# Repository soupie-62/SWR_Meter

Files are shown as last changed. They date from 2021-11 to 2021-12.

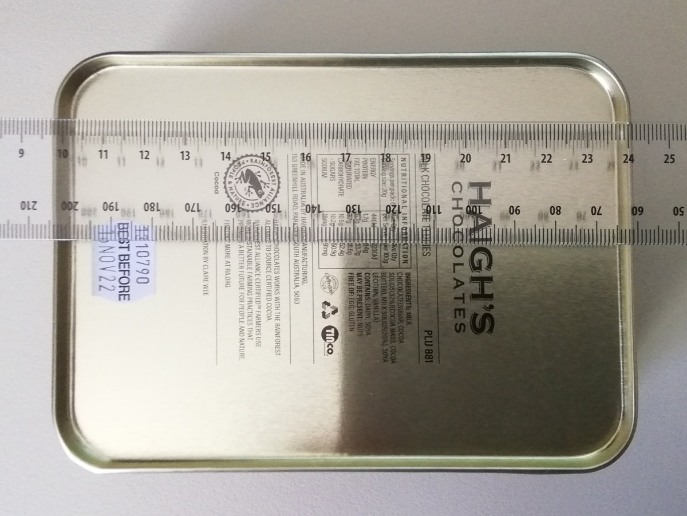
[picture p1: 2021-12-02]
Notes/10cm_12cm_Container_2.jpg

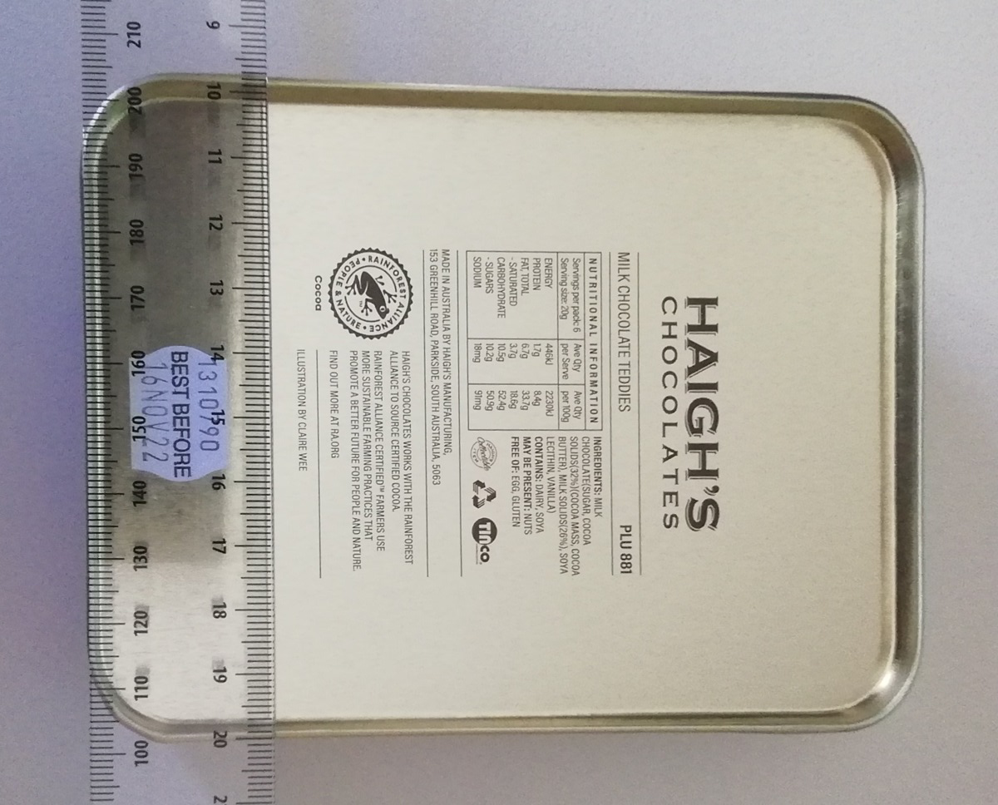
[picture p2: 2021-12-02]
Notes/10cm_12cm_Container_1.jpg

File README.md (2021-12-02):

# SWR_Meter
Notes on an SWR meter. Directional coupler PCB

If you want to truly understand something, try building it. In this, I'm trying to understand directional couplers, as used in SWR meters.

The most basic version is a "sensor" track, very close to the main PCB track. This is only good when the length of track is a significant portion of frequency wavelength.
You could make the PCB longer, but the size limit for cheap PCBs is 10cm x 10cm (4 inch x 4 inch old scale).

At lower frequencies, the "stockton" circuit uses toroid transformers to sense the source voltage and current. The frequency range becomes a function of the toroids used.

My circuit:
I want to create coils from PCB tracks, keeping the Stockton design but eliminating the toroidal transformers. 

SWR_pcb_V2-3

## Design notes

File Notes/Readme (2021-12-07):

Assorted files saved here
PCB Spiral from: https://www.semanticscholar.org/paper/Compact-monolithic-spiral-quadrature-coupler-design-Tabarani-Schumacher/7f18878f872b617d588d85db786c9b51f7185a0d

07 Dec 2021:
Facebook KICAD User Group member, Enrico Lia, has modelled the board using Sonnet and CST Studio.
Results are added

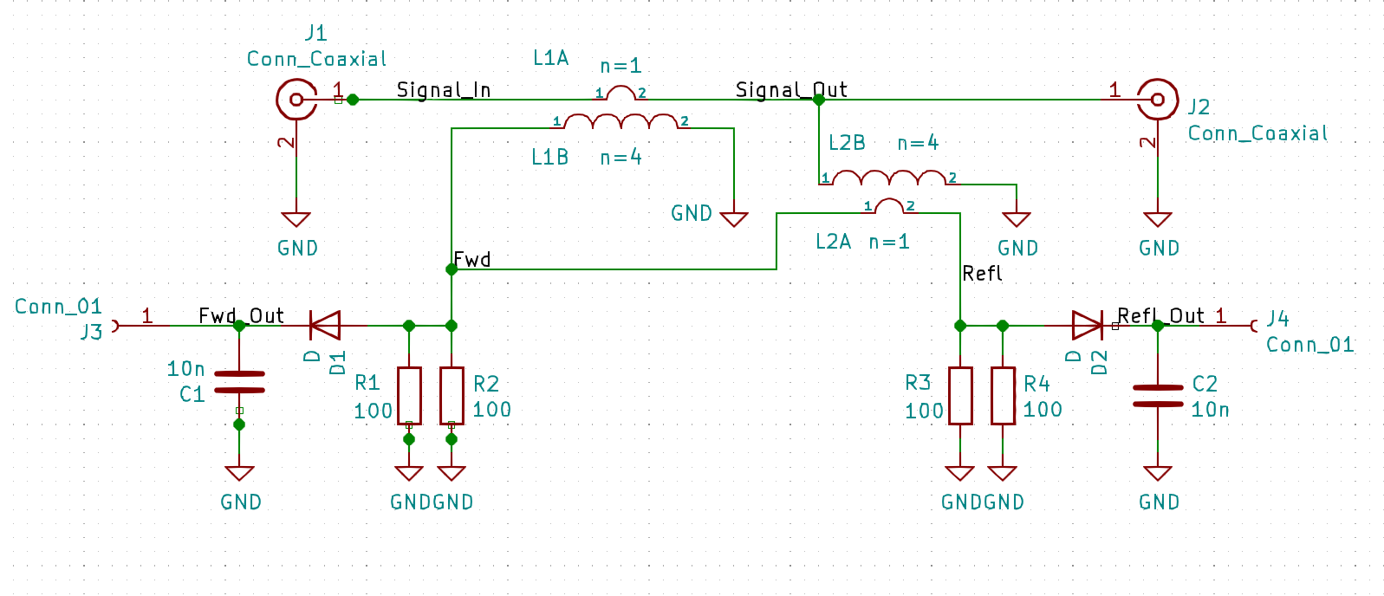
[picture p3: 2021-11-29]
Ver_2/Schematic_KiCad.png

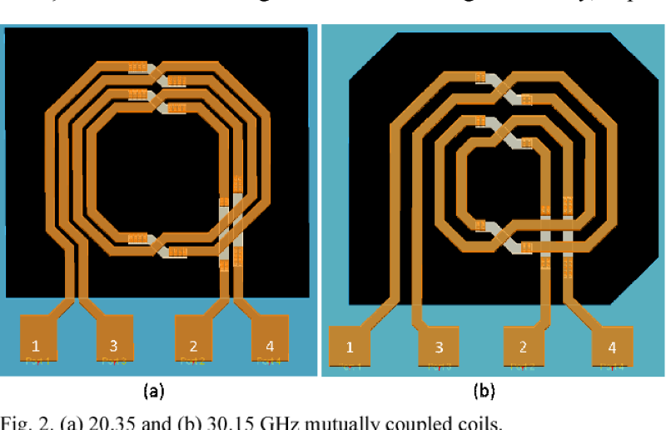
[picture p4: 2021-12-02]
Notes/Spiral_SAMPLE_20GHz.png

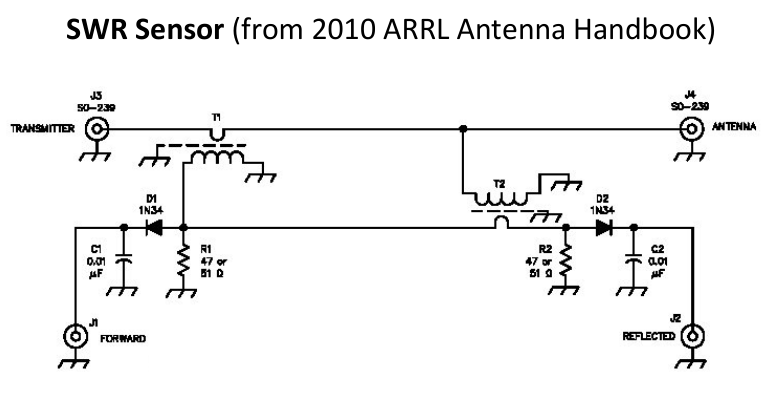
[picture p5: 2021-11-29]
Notes/circuit-02-ARRL.png

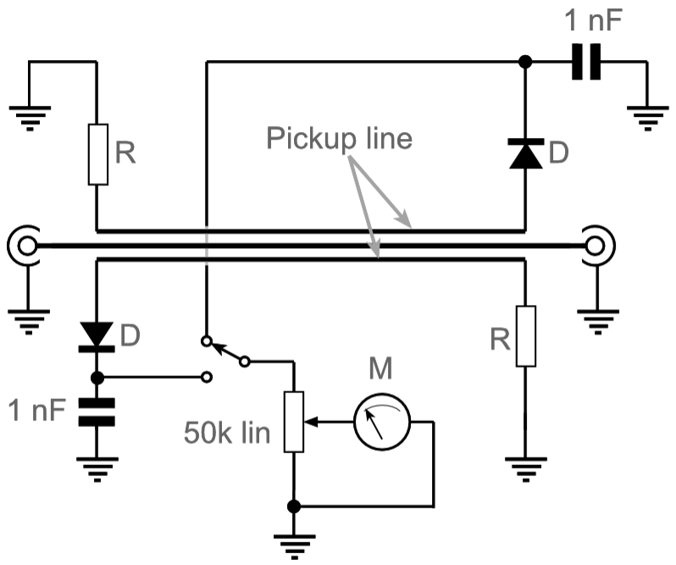
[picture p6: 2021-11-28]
Notes/circuit-01-vswr.png

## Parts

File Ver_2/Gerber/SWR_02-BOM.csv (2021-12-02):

Comment | Designator | Footprint | JLCPCB Part #?optional?
Conn_Coaxial | J1
Conn_Coaxial | J2
100 Ohm | R1 | 2010 SMD | C50472
100 Ohm | R2 | 2010 SMD | C50472
100 Ohm | R3 | 2010 SMD | C50472
100 Ohm | R4 | 2010 SMD | C50472
10nF | C1 | 1812 SMD | C426626
10nF | C2 | 1812 SMD | C426626
BAT46 | D2 | SOD123 | C283255
BAT46 | D1 | SOD123 | C283255
Conn_01x01_Female | J4
Conn_01x01_Female | J3

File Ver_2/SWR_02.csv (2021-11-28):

Reference | Value | Footprint | Datasheet
J1 | Conn_Coaxial |  | ~
J2 | Conn_Coaxial |  | ~
R4 | 100 |  | ~
R3 | 100 |  | ~
R1 | 100 |  | ~
R2 | 100 |  | ~
D2 | D |  | ~
D1 | D |  | ~
C1 | 10n |  | ~
C2 | 10n |  | ~
J4 | Conn_01x01_Female |  | ~
J3 | Conn_01x01_Female |  | ~

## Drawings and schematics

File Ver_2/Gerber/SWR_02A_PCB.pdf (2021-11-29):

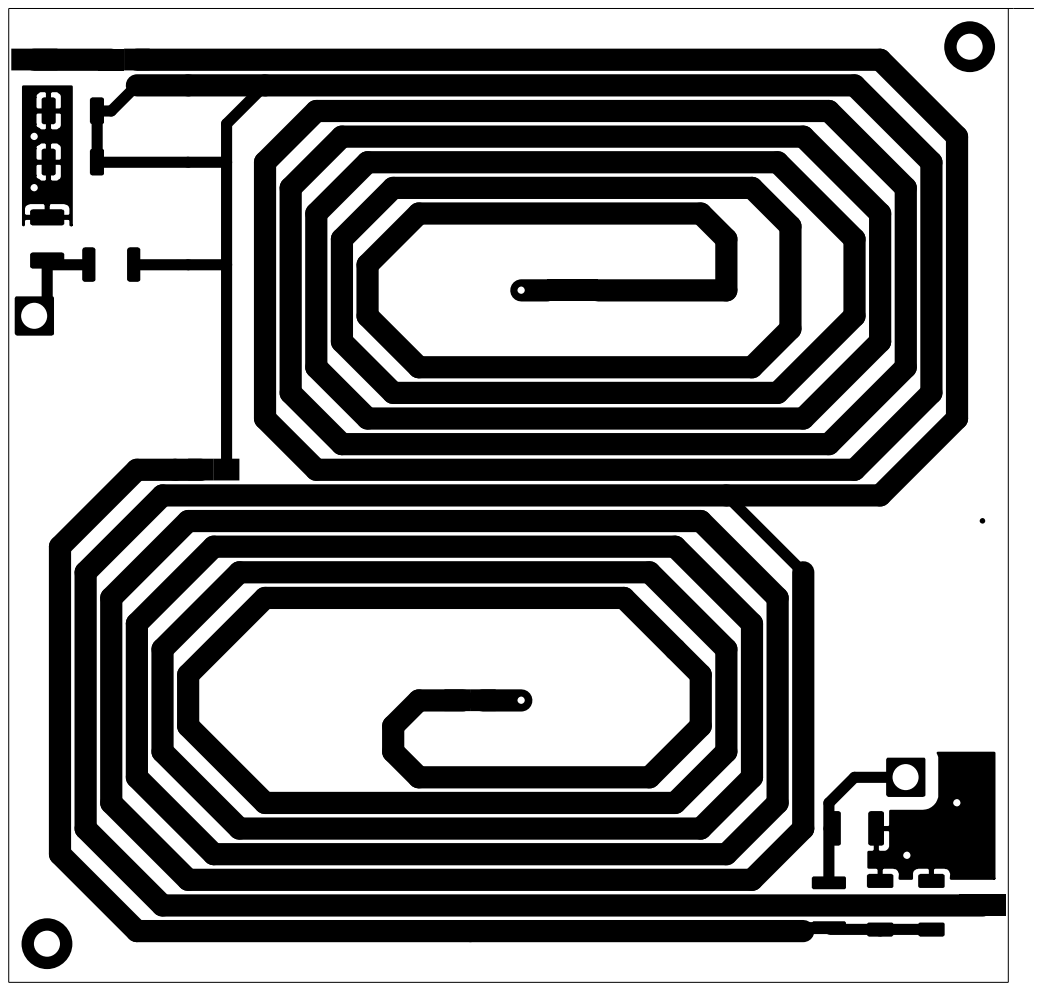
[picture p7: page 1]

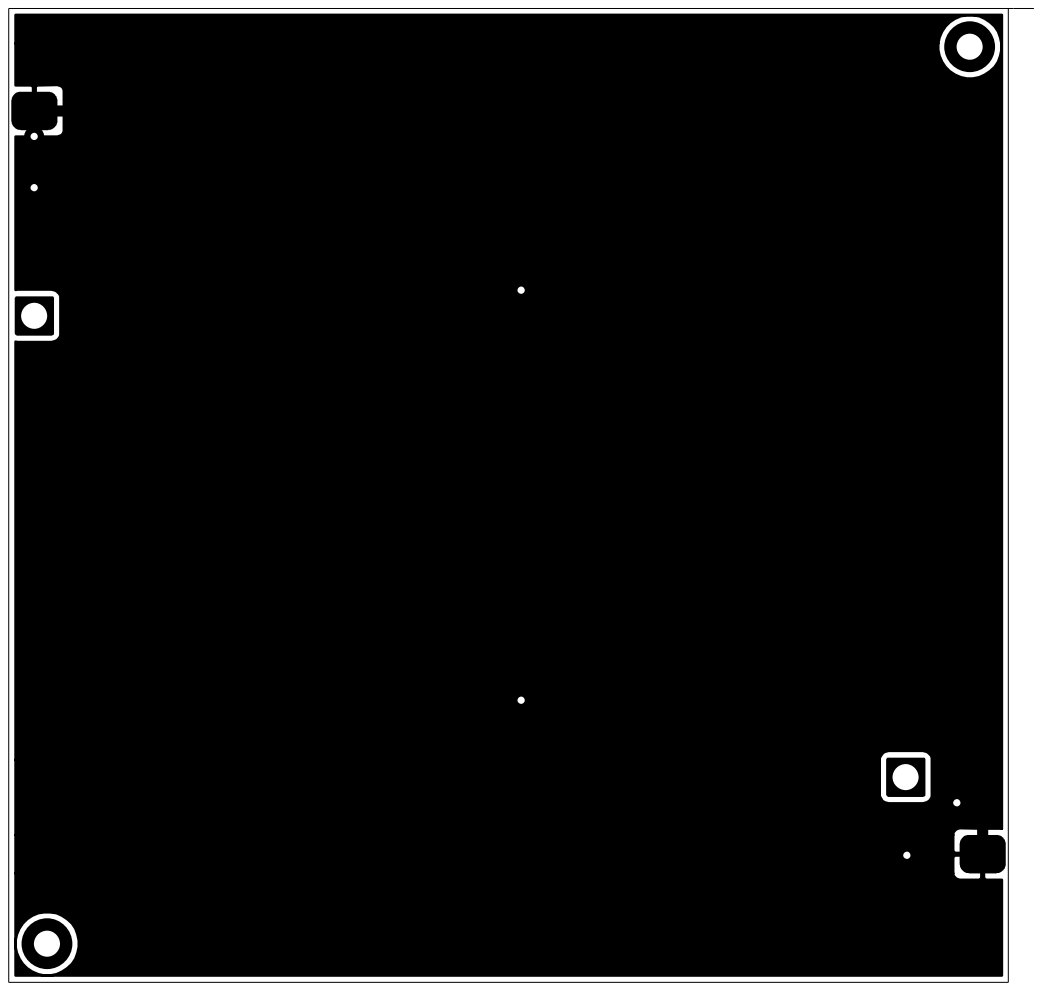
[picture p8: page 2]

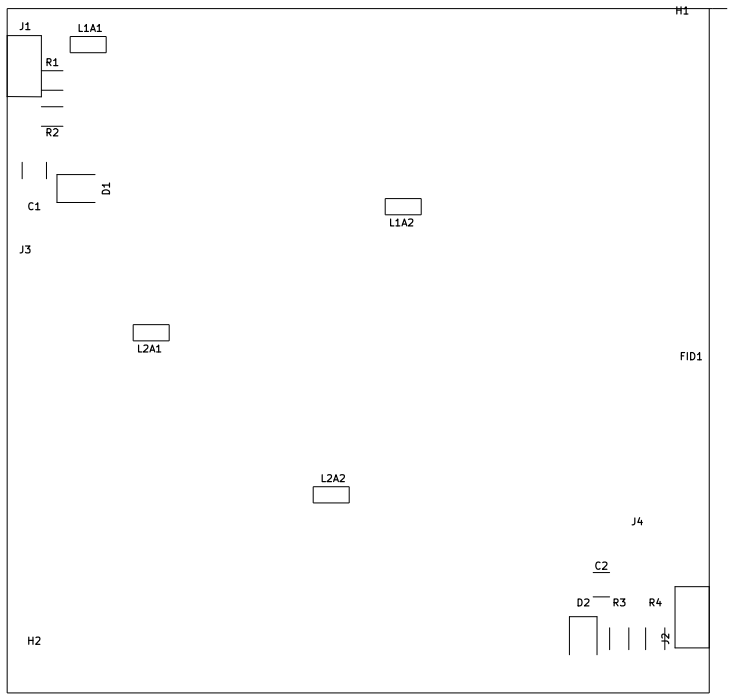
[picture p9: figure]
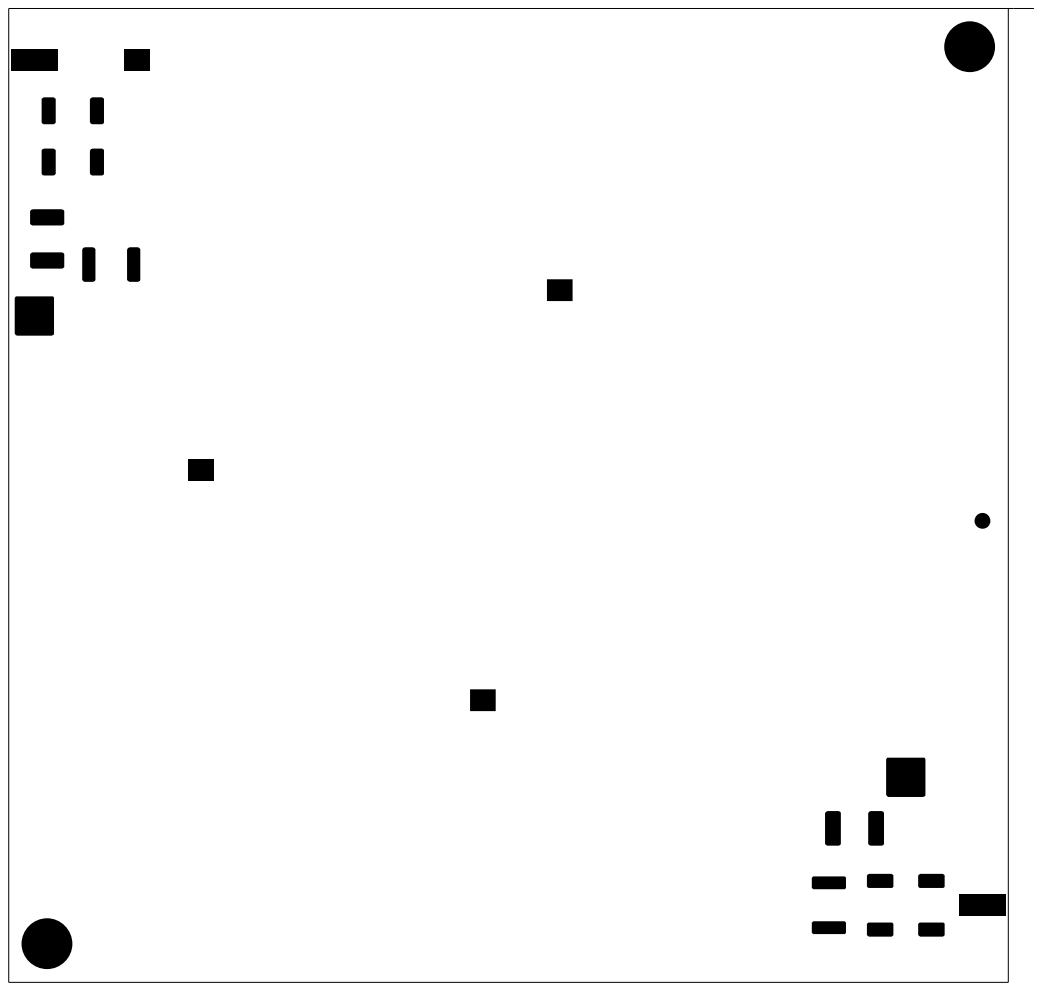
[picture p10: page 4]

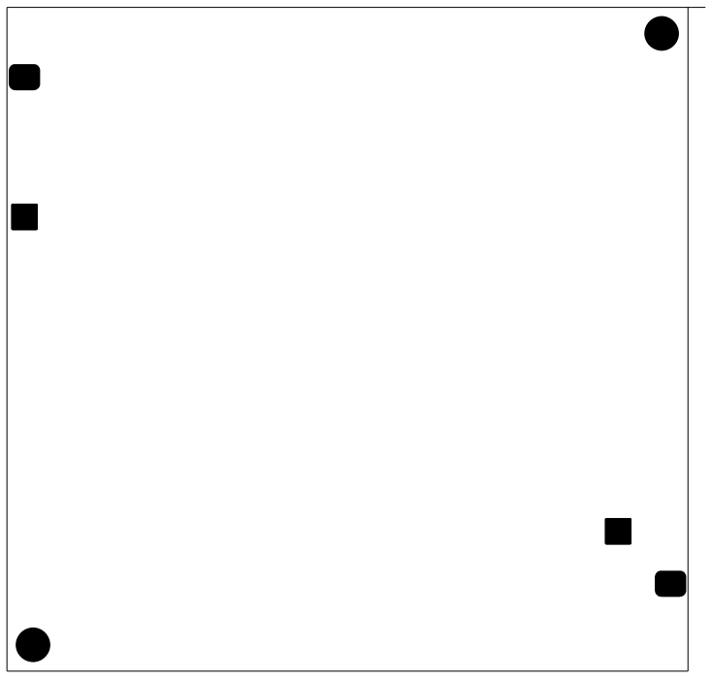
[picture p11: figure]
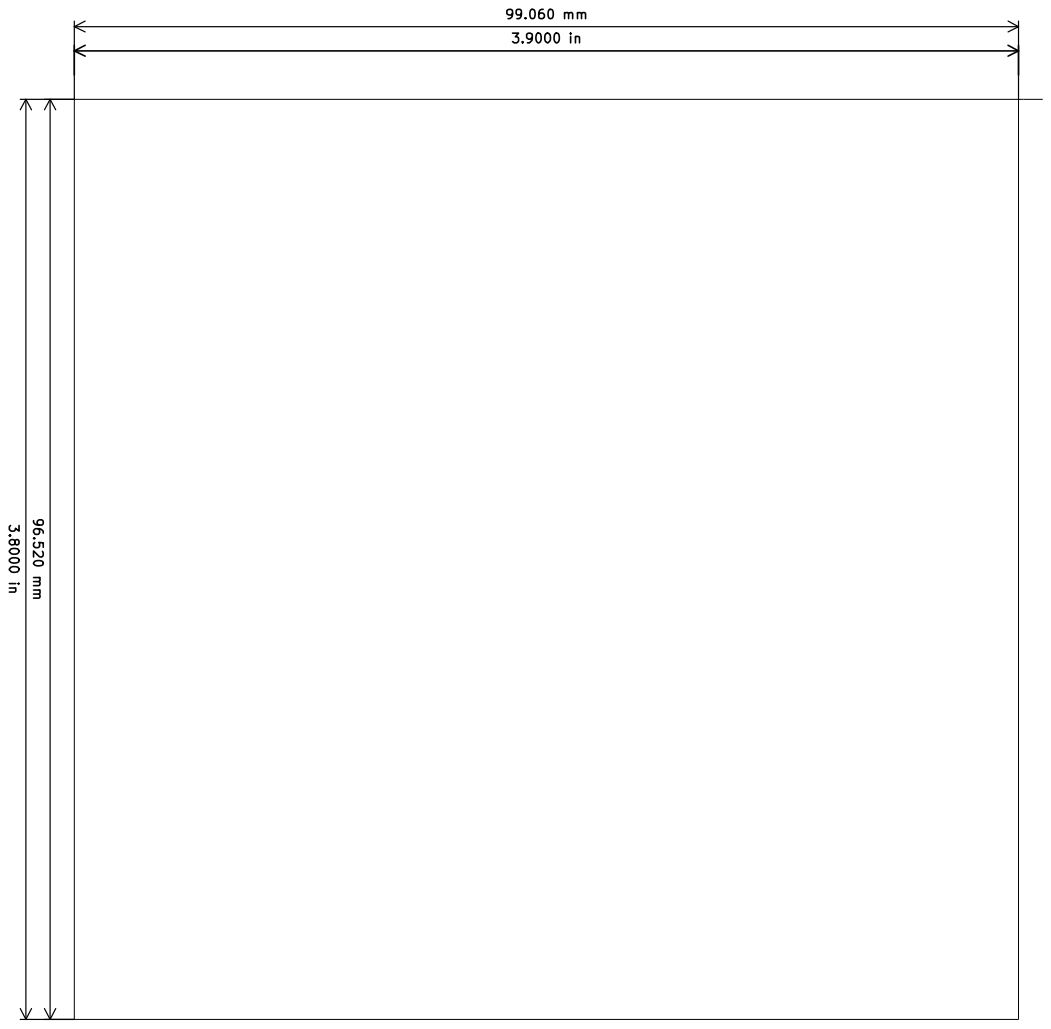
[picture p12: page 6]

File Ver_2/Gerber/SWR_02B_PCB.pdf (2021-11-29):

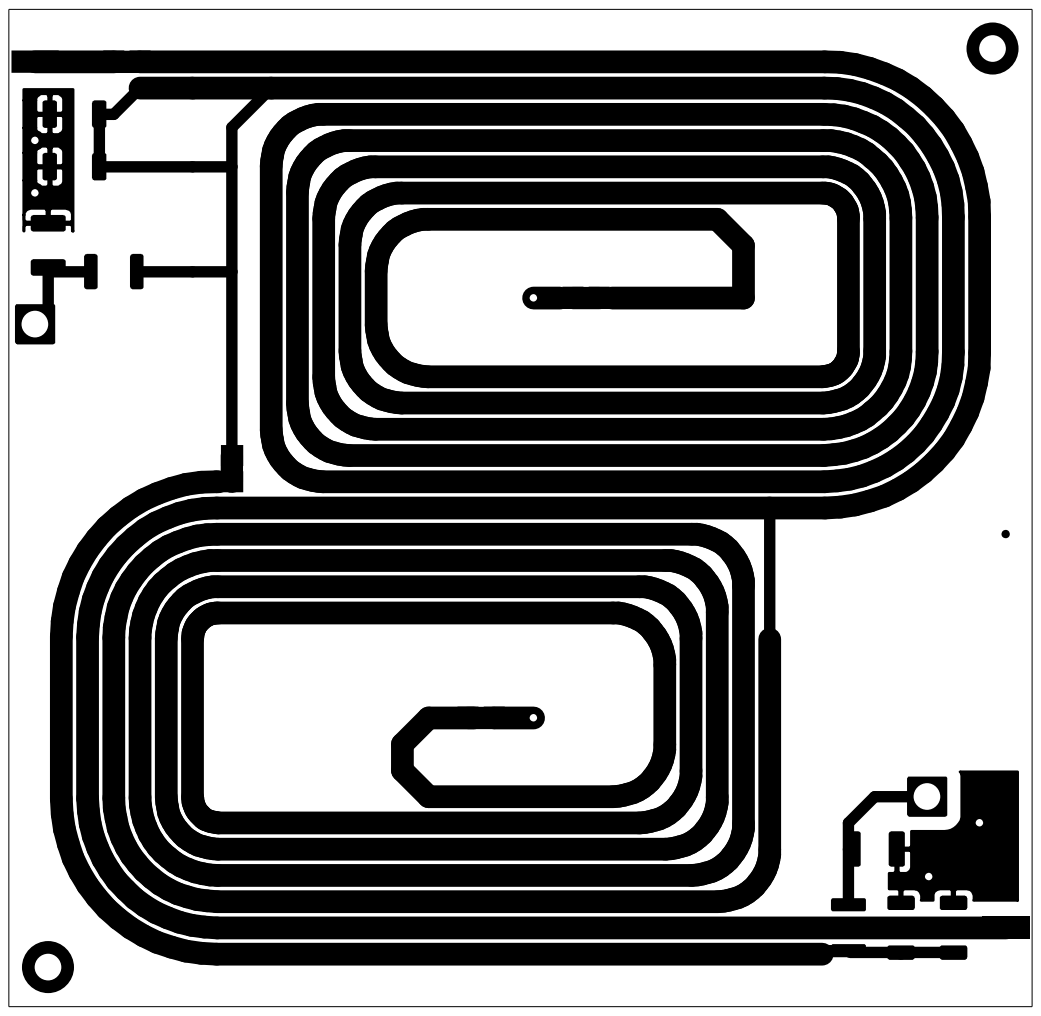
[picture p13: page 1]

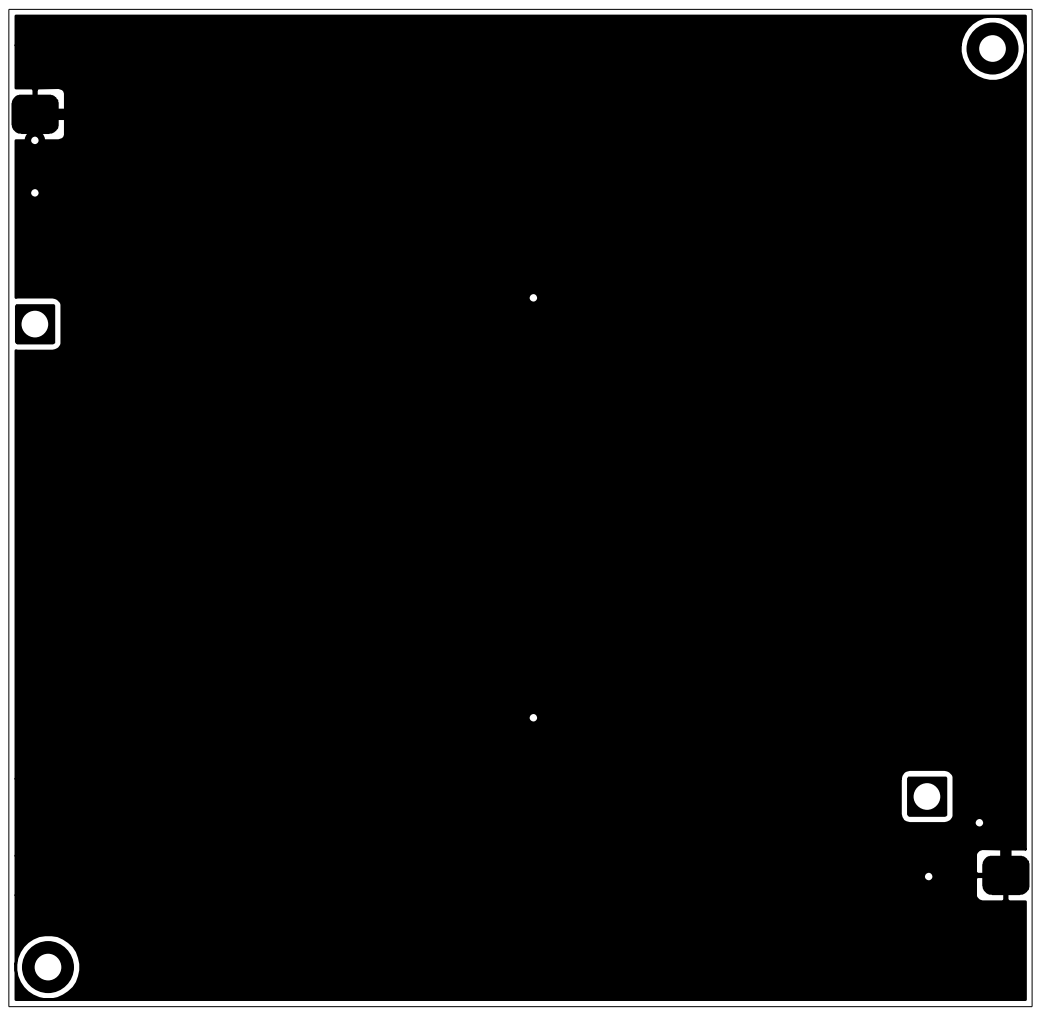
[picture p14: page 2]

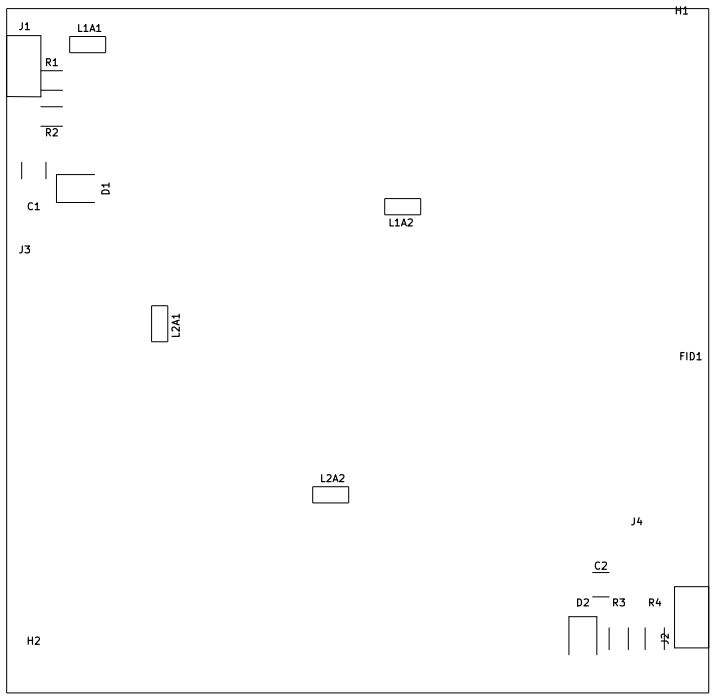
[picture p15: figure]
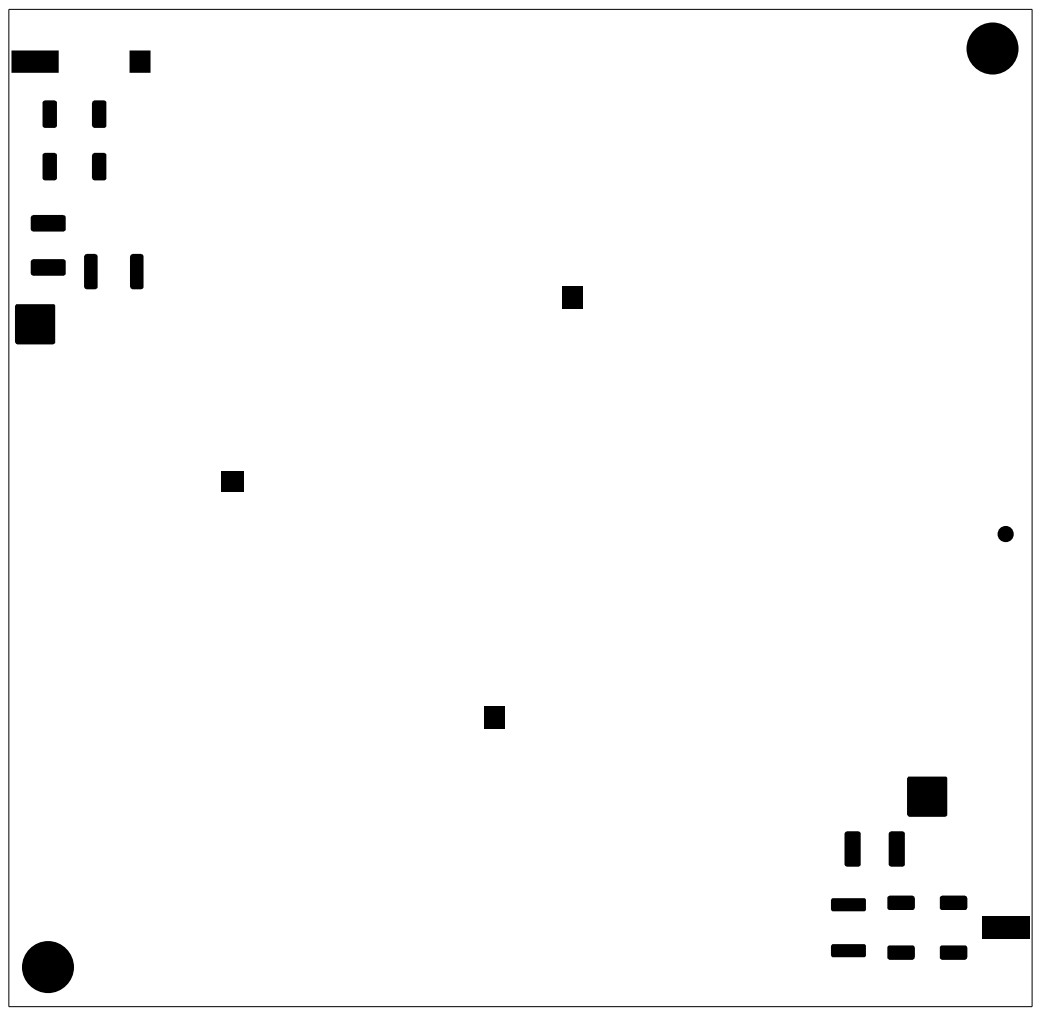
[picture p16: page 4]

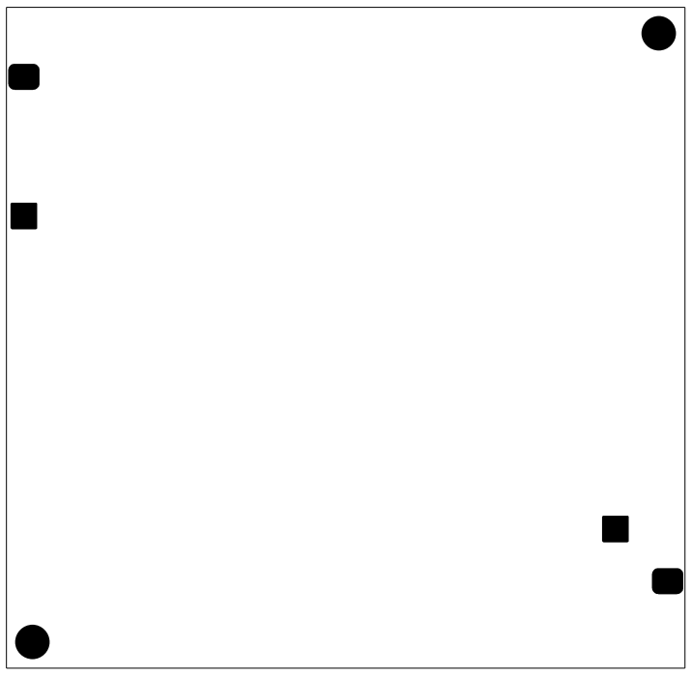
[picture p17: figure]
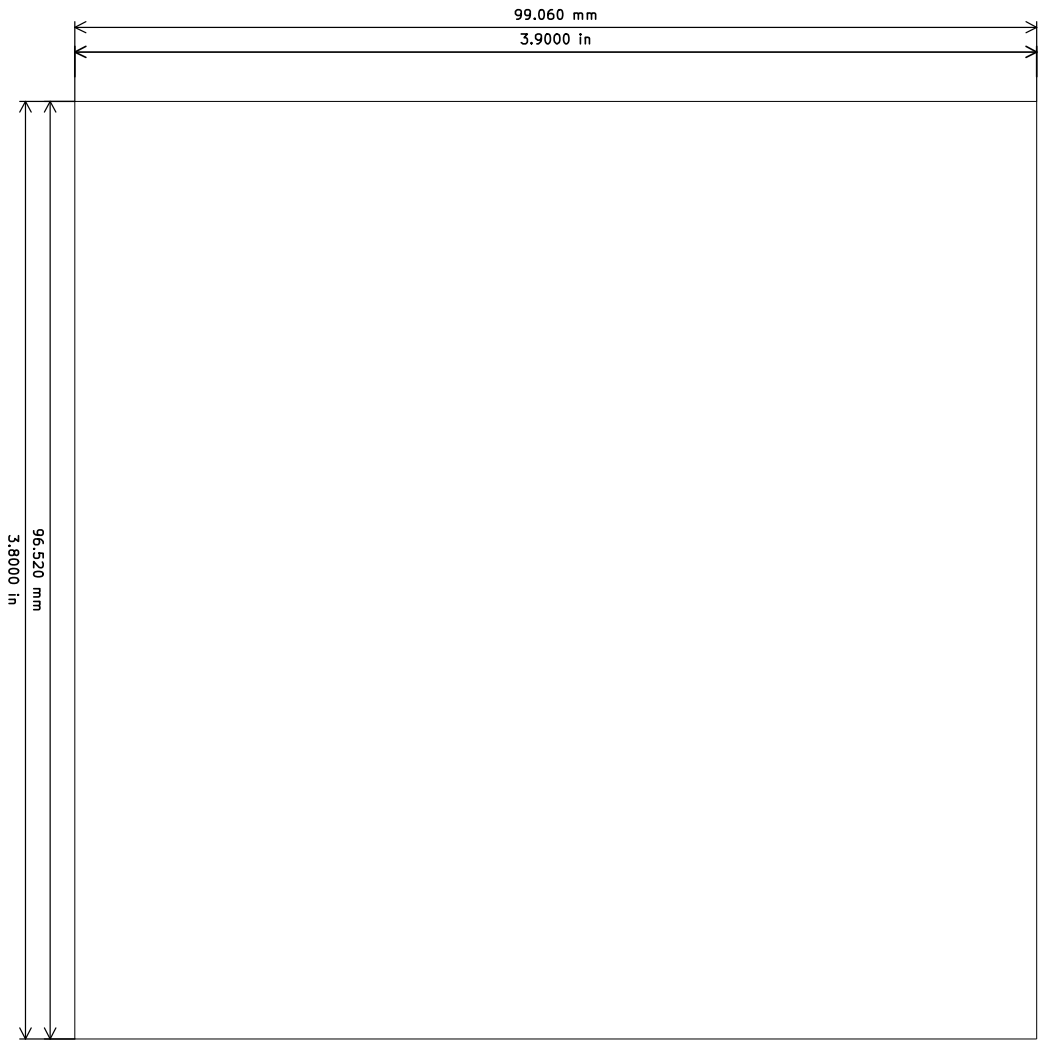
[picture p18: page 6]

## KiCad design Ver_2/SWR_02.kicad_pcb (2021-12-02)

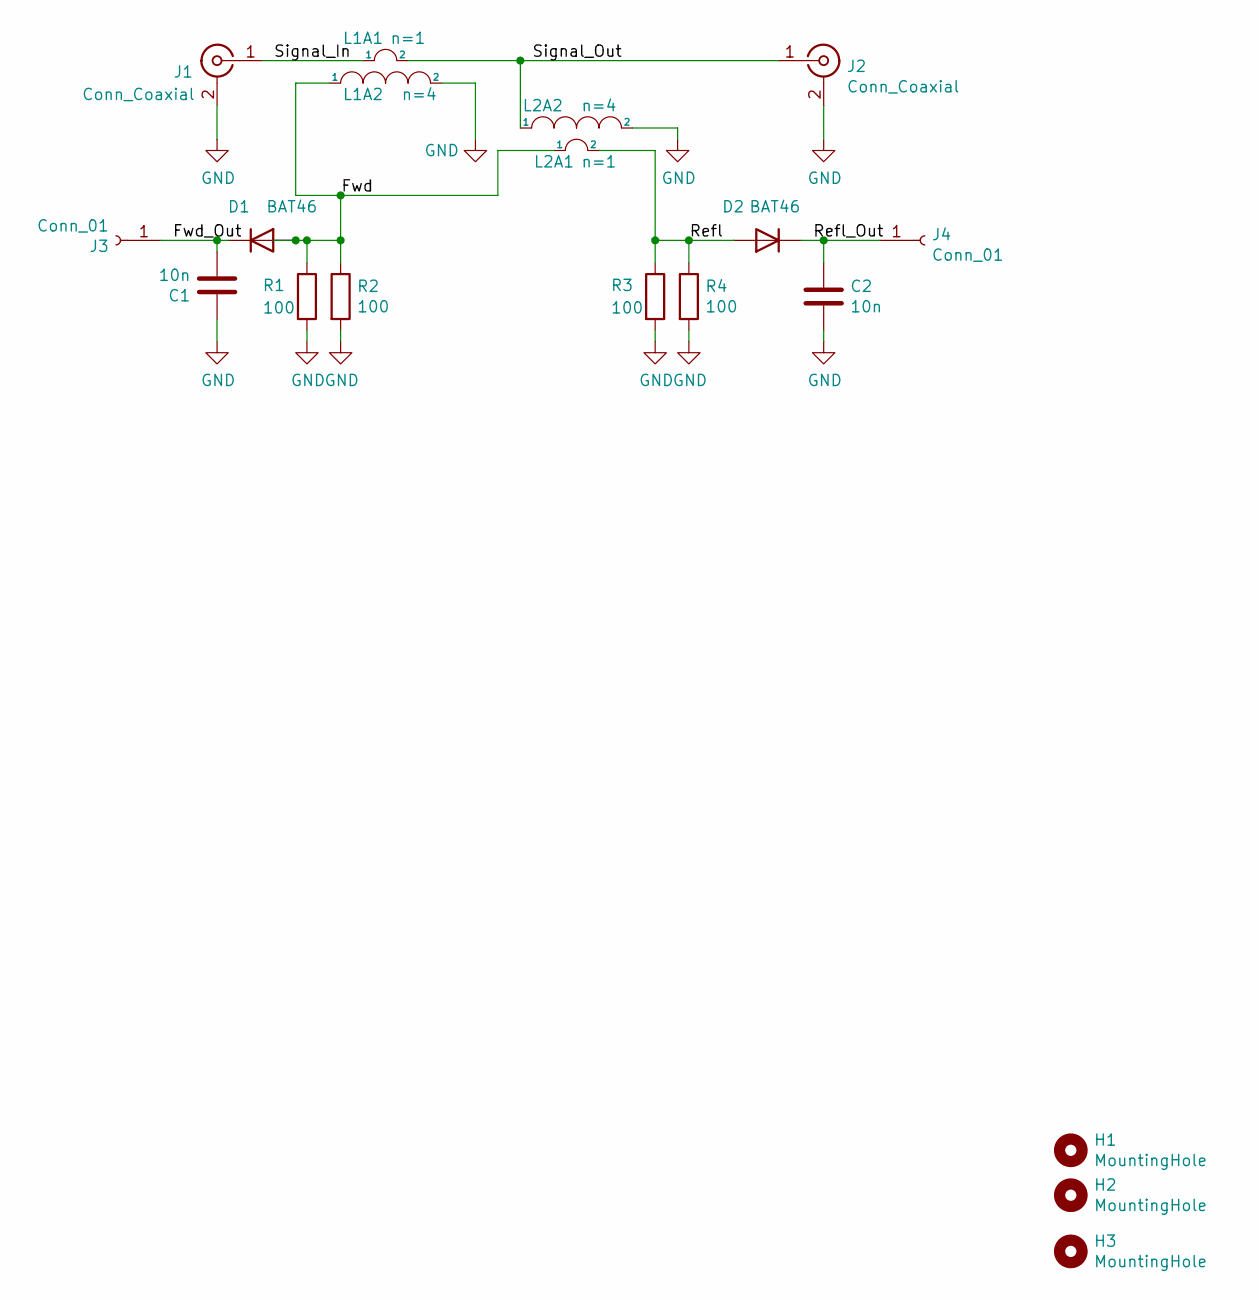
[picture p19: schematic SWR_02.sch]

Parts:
C1, C2: 10n; C_1812_4532Metric_Pad1.57x3.40mm_HandSolder
D1, D2: BAT46; D_SOD-123
H1, H2, H3: MountingHole; MountingHole_2.5mm_Pad_TopBottom
J1, J2: Conn_Coaxial; BNC_Custom_01_SMT
J3, J4: Conn_01; SolderWire-0.75sqmm_1x01_D1.25mm_OD2.3mm
L1A1, L2A1: n=1; Coil_PCB_85mil
L1A2, L2A2: n=4; Coil_PCB_85mil
R1, R2, R3, R4: 100; R_2010_5025Metric_HandSolder

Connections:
/Fwd: D1.2 (A), L1A2.1, L2A1.1, R1.1, R2.1
/Fwd_Out: C1.2, D1.1 (K), J3.1
/Refl: D2.2 (A), L2A1.2, R3.1, R4.1
/Refl_Out: C2.1, D2.1 (K), J4.1
/Signal_In: J1.1 (In), L1A1.1
/Signal_Out: J2.1 (In), L1A1.2, L2A2.1
GND: C1.1, C2.2, J1.2 (Ext), J2.2 (Ext), L1A2.2, L2A2.2, R1.2, R2.2, R3.2, R4.2

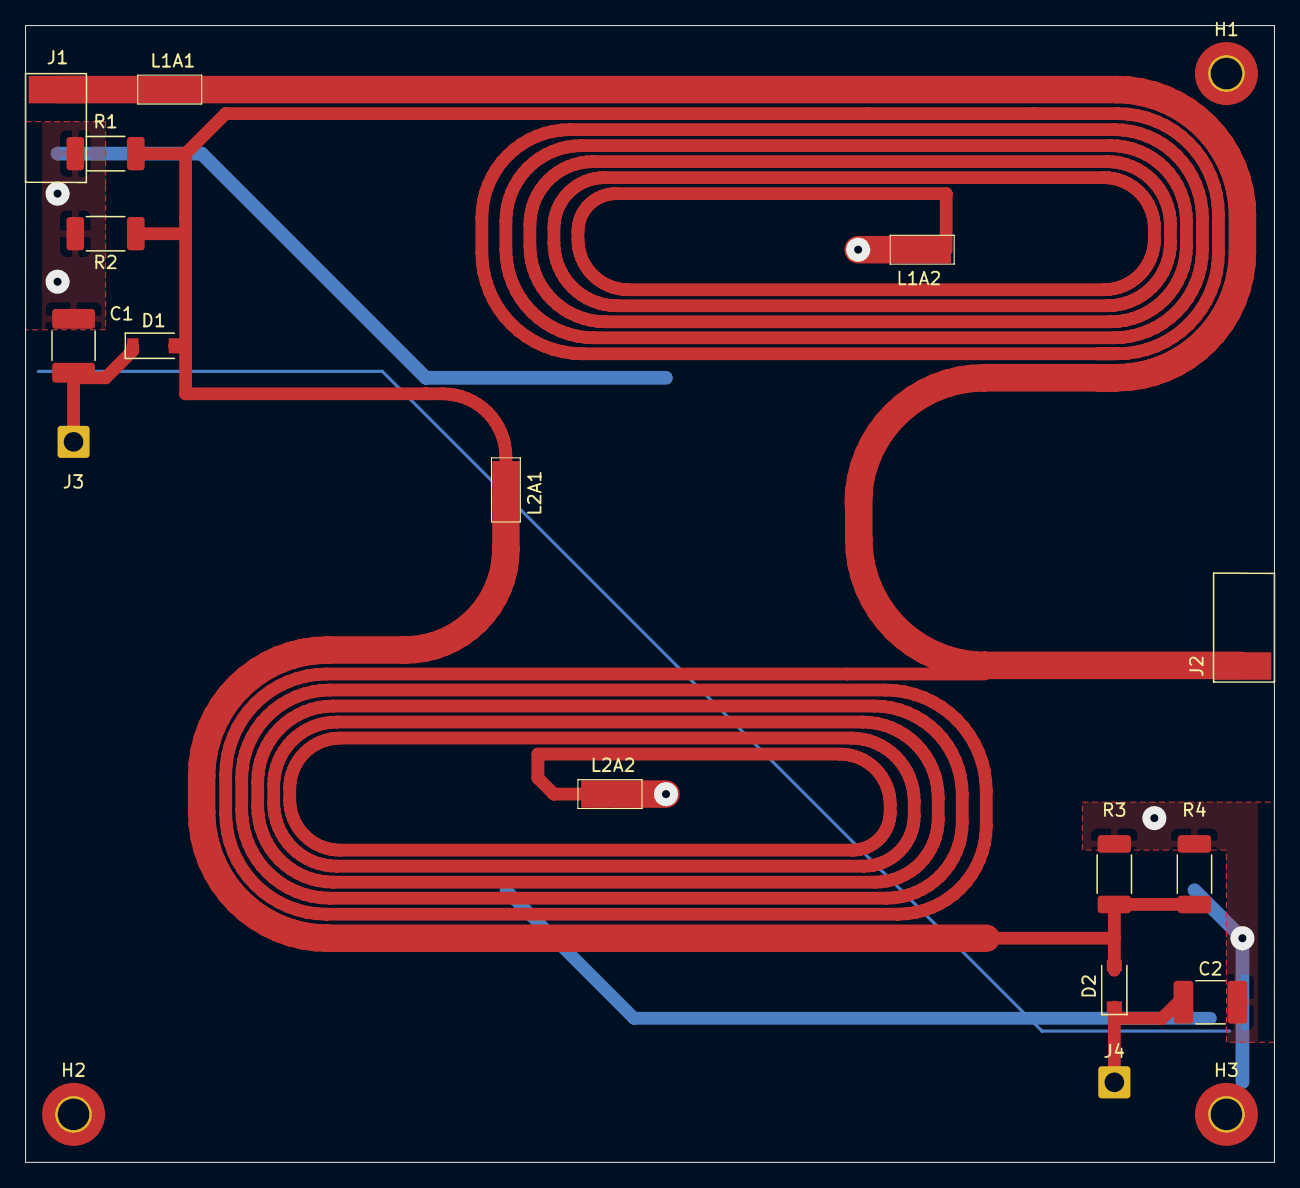
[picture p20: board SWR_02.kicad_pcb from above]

Board: 2 copper layers, 99.1 x 90.2 mm, 19 parts (0 on the bottom side), 7 nets.

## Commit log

2021-11-28 Update Readme
    Source of PCB Spiral image
2021-11-28 Create Ver_1
    Kicad files for version 1 go here
2021-11-28 Add files via upload
    Kicad files added
    [SWR_01.csv, SWR_01.kicad_pcb, SWR_01.sch]
2021-11-29 Update README.md
    Added PCB Image
2021-11-29 Add files via upload
    Version 2 has curved tracks
    [SWR_02-B_Cu.gbr, SWR_02-B_Mask.gbr, SWR_02-B_Paste.gbr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]
2021-12-02 Delete Ver_1 directory
    Removed old version 1
    [SWR_01.csv, SWR_01.kicad_pcb, SWR_01.sch]
2021-12-02 Add files via upload
    Updated files copied to Git
    [SWR_02.kicad_pcb, SWR_02.sch]
2021-12-02 Add files via upload
    Updated Gerber plots
    [SWR_02-BOM.csv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]
2021-12-02 Add files via upload
    Updated notes include datasheets for BOM
